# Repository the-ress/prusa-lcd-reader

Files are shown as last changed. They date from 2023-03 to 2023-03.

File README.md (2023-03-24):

# Prusa LCD Reader

Connects to flat ribbon cable no. 1 of Prusa MK3S or similar, listens to LCD
communication, and sends the text to Home Assistant.

## How it looks

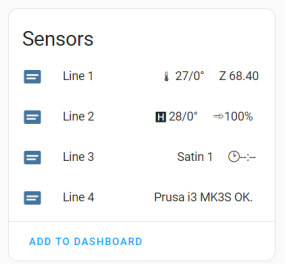
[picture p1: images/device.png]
Screenshot of device sensors line 1 to 4 in Home Assistant.

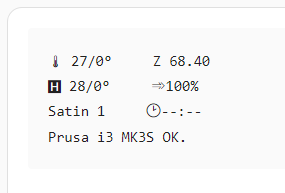
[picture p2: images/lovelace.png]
Screenshot of a Lovelace card mirroring the LCD.


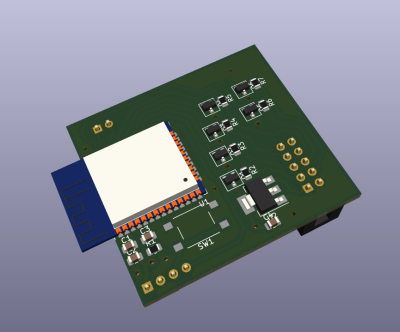
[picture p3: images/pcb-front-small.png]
Rendering of the PCB, front.

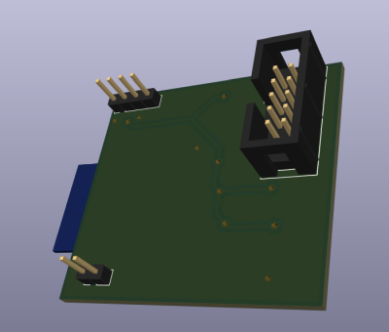
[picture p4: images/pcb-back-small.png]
Rendering of the PCB, back.

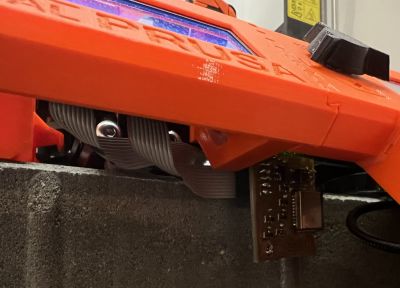
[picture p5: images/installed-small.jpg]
Photo of the board installed on the printer, underneath the LCD assembly.


## Preparing the printer

Get a [10-pin IDC connector](https://www2.mouser.com/ProductDetail/Wurth-Elektronik/61201023021?qs=W%252B2sBeLta1Y7QgcPlTMBZQ%3D%3D)
and carefully attach it to flat ribbon cable no. 1, approximately where you want
the device to go. Make sure the orientation matches the other connectors.

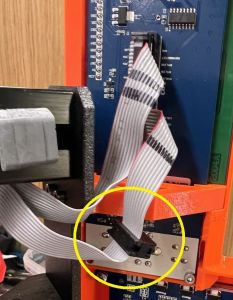
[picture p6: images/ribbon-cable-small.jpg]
Photo of the ribbon cable with the extra connector attached.


## Manufacturing notes

The board design doesn't rely on plated through-holes for the headers. (It still needs
some vias though.)

If you have the board manufactured profesionally, add some vias under pad 39 of
the ESP for better thermal performance.

### Components

- ESP32-WROOM-32
- voltage regulator 5V to 3.3V - SOT-233-3 footprint
- 6 NPN transistors (to protect GPIO from 5V signal) - SOT-23-3 footprint
- various resistors and capacitors - 0805 footprint
- 10-pin IDC connector header
- a reset button (optional)
- additional pin headers for the initial flashing (optional if you can bodge the
  connection without them)

## Sample ESPHome configuration
```yaml
external_components:
  - source: github://the-ress/prusa-lcd-reader@main
    components:
      - prusa_lcd

prusa_lcd:
  data_pins:
    - GPIO21
    - GPIO17
    - GPIO22
    - GPIO16
  enable_pin: GPIO19
  rs_pin: GPIO18
  text_sensors:
    - name: "Line 1"
    - name: "Line 2"
    - name: "Line 3"
    - name: "Line 4"
```

## Sample Lovelace card
````yaml
type: markdown
content: |-
  ```
  {{ states('sensor.printer_lcd_line_1') }}
  {{ states('sensor.printer_lcd_line_2') }}
  {{ states('sensor.printer_lcd_line_3') }}
  {{ states('sensor.printer_lcd_line_4') }}
  ```
````

## Resources
- Decoder code adapted from https://github.com/fsalomon/HD44780-decoder/
- Special characters mapping: https://github.com/prusa3d/Prusa-Firmware/blob/MK3/Firmware/lcd.h#L199
- LCD board docs: https://reprap.org/wiki/RepRapDiscount_Smart_Controller
- Printer main board schematic: https://github.com/ultimachine/Einsy-Rambo/blob/1.1a/board/Project%20Outputs/Schematic%20Prints_Einsy%20Rambo_1.1a.PDF

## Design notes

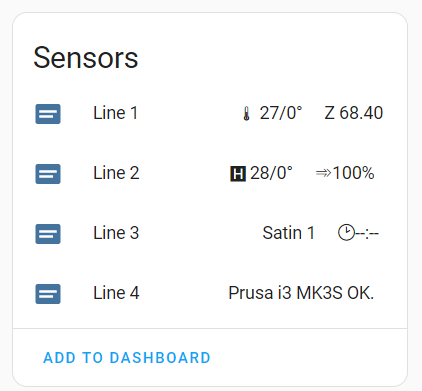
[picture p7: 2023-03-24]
images/2device.png

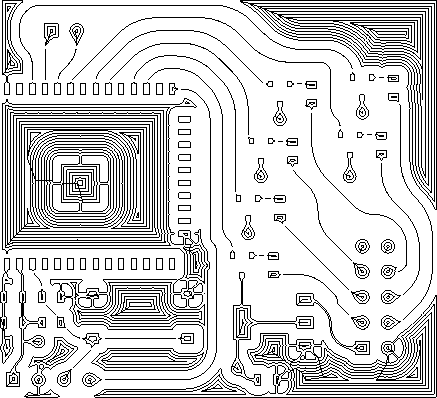
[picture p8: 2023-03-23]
other/prusa-lcd-reader-rounded-F_Cu.gbr_mt_paint_cnc_adjusted.png

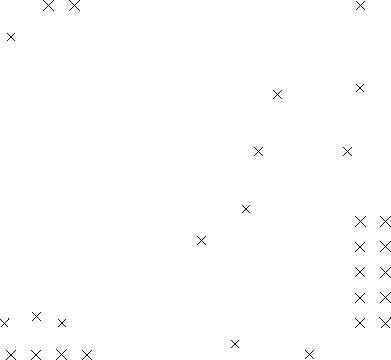
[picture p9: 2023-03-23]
other/prusa-lcd-reader-rounded_drill.png

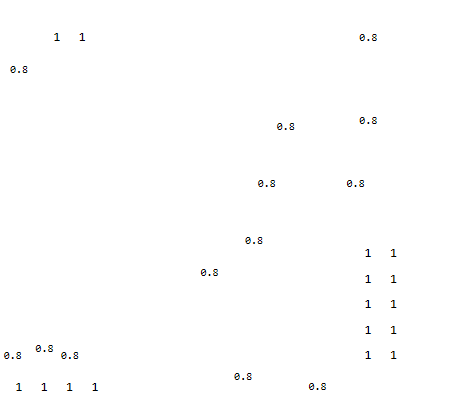
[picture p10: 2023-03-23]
other/prusa-lcd-reader-rounded_drill_map.png

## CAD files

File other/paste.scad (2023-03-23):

//mirror([0, 0, 1]) // B
stencil();

module edge(){
    import("Edge_Cuts.gbr_svg.svg");
}

module paste(){
    difference(){
        import("F_Paste.gbr_iso_joined_svg.svg");
        edge();
    }
}

module pins(){
    difference(){
        import("drl_edit_conv_joined_svg.svg");
        edge();
    }
}

module stencil(){
    union(){
        difference(){
            hull(){
                linear_extrude(height = 0.15) {
                    offset(5) edge();
                }
            }
            linear_extrude(height = 1, center = true) {
                    paste();
            }
        }
        translate([0, 0, -.45]){
            linear_extrude(height = .45) {
                pins();
            }
        }
//        translate([0, 0, 0.125 + 0.10]){
//            hull(){
//                linear_extrude(height = 0.2) {
//                    edge();
//                }
//            }
//        }
    }
}

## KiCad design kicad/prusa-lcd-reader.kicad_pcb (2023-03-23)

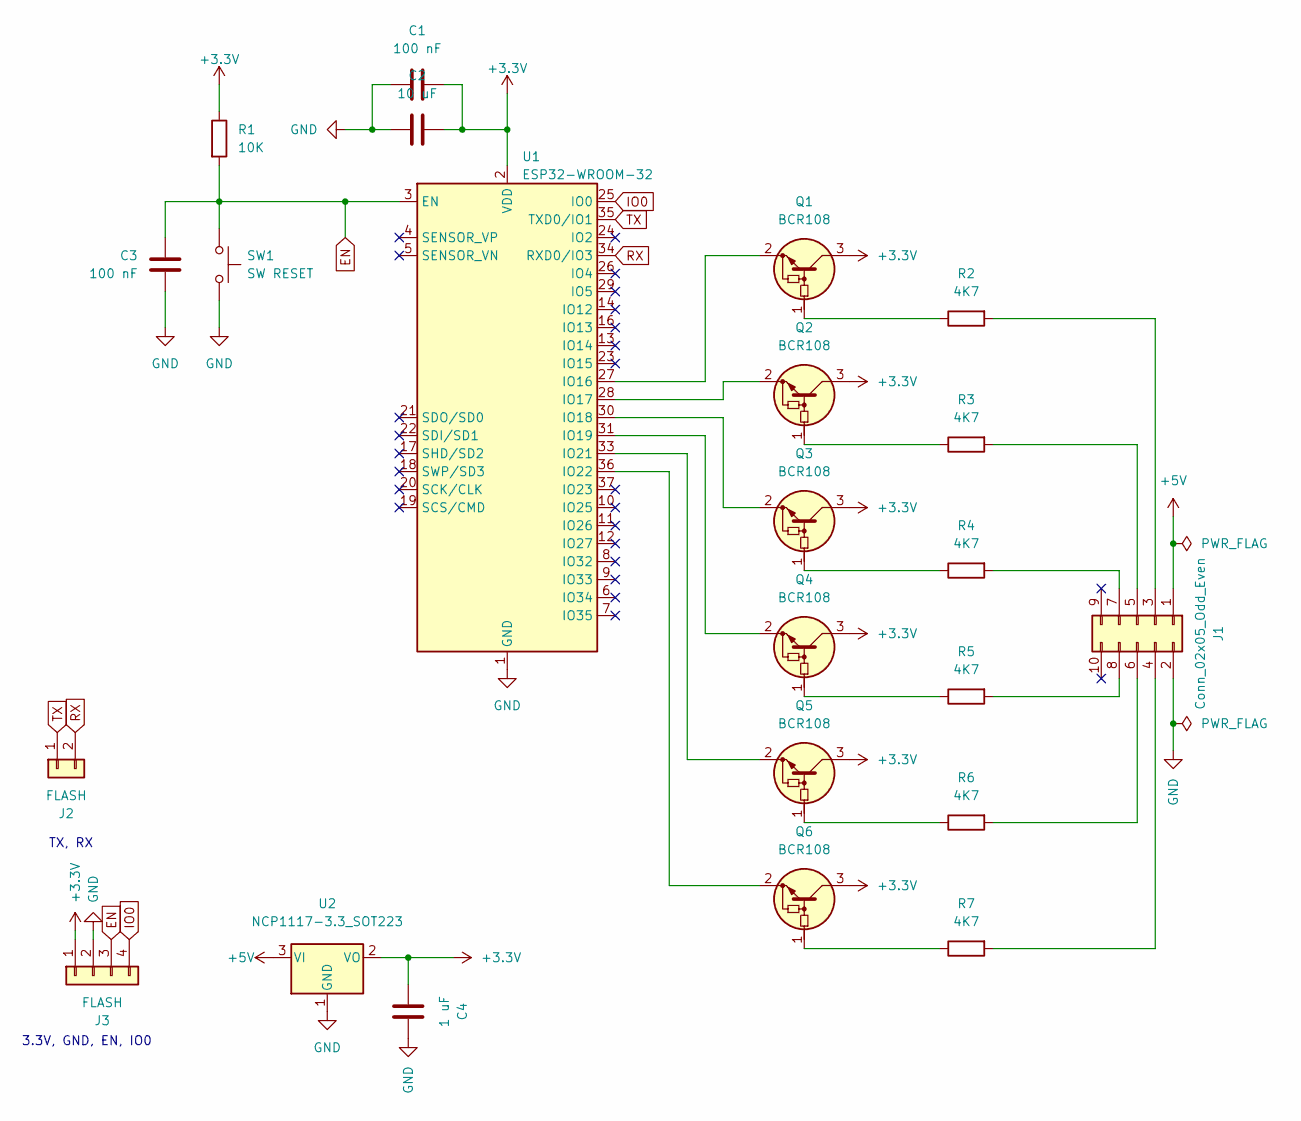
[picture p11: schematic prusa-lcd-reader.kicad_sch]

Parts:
C1, C3: 100 nF; C_0805_2012Metric
C2: 10 uF; C_0805_2012Metric
C4: 1 uF; C_0805_2012Metric
J1: Conn_02x05_Odd_Even
J2: FLASH; PinHeader_1x02_P2.54mm_Vertical
J3: FLASH; PinHeader_1x04_P2.54mm_Vertical
Q1, Q2, Q3, Q4, Q5, Q6: BCR108; SOT-23
R1: 10K; R_0805_2012Metric
R2, R3, R4, R5, R6, R7: 4K7; R_0805_2012Metric
SW1: SW RESET; SW_Push_TD-03XA-T
U1: ESP32-WROOM-32
U2: NCP1117-3.3_SOT223; SOT-223-3_TabPin2

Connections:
+3.3V: C1.2, C2.2, C4.1, J3.1, Q1.3 (C), Q2.3 (C), Q3.3 (C), Q4.3 (C), Q5.3 (C), Q6.3 (C), R1.1, U1.2 (VDD), U2.2 (VO)
+5V: J1.1, U2.3 (VI)
EN: C3.1, J3.3, R1.2, SW1.1, U1.3 (EN)
GND: C1.1, C2.1, C3.2, C4.2, J1.2, J3.2, SW1.2, U1.1 (GND), U1.15 (GND), U1.38 (GND), U1.39 (GND), U2.1 (GND)
IO0: J3.4, U1.25 (IO0)
unnamed: J1.3, R2.2
unnamed: J1.4, R7.2
unnamed: J1.5, R3.2
unnamed: J1.6, R6.2
unnamed: J1.7, R4.2
unnamed: J1.8, R5.2
unnamed: Q1.1 (B), R2.1
unnamed: Q1.2 (E), U1.27 (IO16)
unnamed: Q2.1 (B), R3.1
unnamed: Q2.2 (E), U1.28 (IO17)
unnamed: Q3.1 (B), R4.1
unnamed: Q3.2 (E), U1.30 (IO18)
unnamed: Q4.1 (B), R5.1
unnamed: Q4.2 (E), U1.31 (IO19)
unnamed: Q5.1 (B), R6.1
unnamed: Q5.2 (E), U1.33 (IO21)
unnamed: Q6.1 (B), R7.1
unnamed: Q6.2 (E), U1.36 (IO22)
RX: J2.2, U1.34 (RXD0/IO3)
TX: J2.1, U1.35 (TXD0/IO1)

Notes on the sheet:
3.3V, GND, EN, IO0
TX, RX

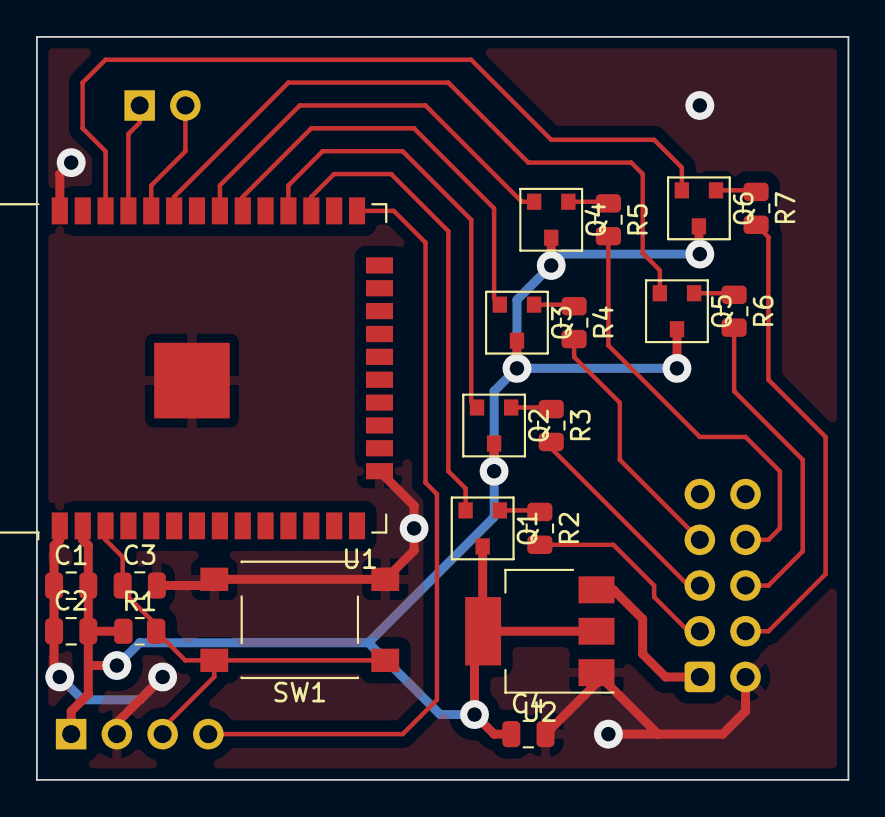
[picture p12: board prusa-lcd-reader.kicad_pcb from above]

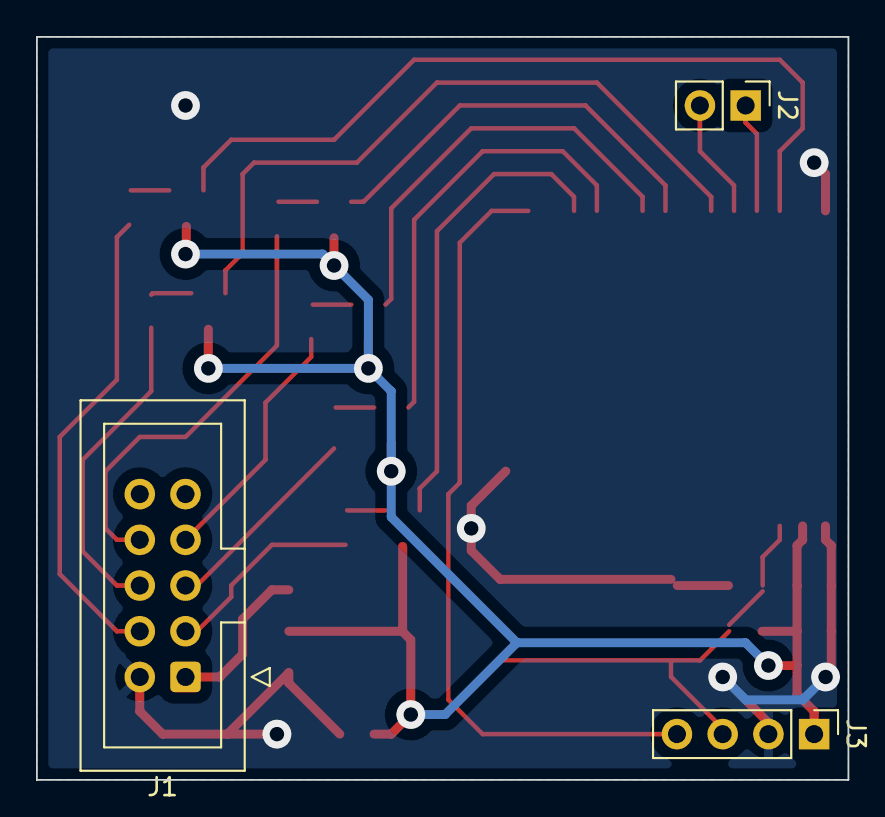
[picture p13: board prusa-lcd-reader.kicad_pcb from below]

Board: 2 copper layers, 45.1 x 41.3 mm, 23 parts (3 on the bottom side), 25 nets.

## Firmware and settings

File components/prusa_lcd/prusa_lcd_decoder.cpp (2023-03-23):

#include "prusa_lcd_decoder.h"

#include <freertos/task.h>
#include "esphome/core/log.h"

namespace esphome {
namespace prusa_lcd {

static const char *const TAG = "prusa_lcd";

void PrusaLcdDecoder::setup() {
  interruptQueue_ = xQueueCreate(64, sizeof(int));
  xTaskCreate(decodeTask_, "DecodeTask", 2048, this, 1, NULL);

	gpio_set_intr_type(enable_pin_, GPIO_INTR_NEGEDGE);
	gpio_intr_enable(enable_pin_);

  gpio_install_isr_service(0);
  gpio_isr_handler_add(enable_pin_, gpioInterruptHandler_, this);
}

void PrusaLcdDecoder::gpioInterruptHandler_(void *arg) {
  PrusaLcdDecoder *obj = (PrusaLcdDecoder*)arg;

  uint8_t rs = gpio_get_level(obj->rs_pin_);
  uint8_t d7 = gpio_get_level(obj->d7_pin_);
  uint8_t d6 = gpio_get_level(obj->d6_pin_);
  uint8_t d5 = gpio_get_level(obj->d5_pin_);
  uint8_t d4 = gpio_get_level(obj->d4_pin_);

  uint8_t data = (rs << 7) + (d7 << 3) + (d6 << 2) + (d5 << 1) + d4;
  xQueueSendFromISR(obj->interruptQueue_, &data, NULL);
}

void PrusaLcdDecoder::decodeTask_(void *arg) {
  PrusaLcdDecoder *obj = (PrusaLcdDecoder*)arg;

  uint8_t data;
  while (true) {
    if (xQueueReceive(obj->interruptQueue_, &data, portMAX_DELAY)) {
      obj->decode_(data & 0xF, data >> 7);
    }
  }
}

void PrusaLcdDecoder::decode_(uint8_t data, bool rs) {
  if (gotUpperNibble_) {
    data = (upperNibble_ << 4 | data);
    gotUpperNibble_ = false;
  } else {
    upperNibble_ = data;
    gotUpperNibble_ = true;
    return;
  }
  if (rs == 1) {
    // store received byte
    if (receivingCgram_) {
      CGRAM[cgramIndex_] = data;
      cgramIndex_ = (cgramIndex_ + 1) % CGRAM_SIZE;
    } else if (receivingDdram_) {
      DDRAM[ddramIndex_] = data;
      ddramIndex_ = (ddramIndex_ + 1) % DDRAM_SIZE;
    }
  } else {
    // command received
    evalCommand_(data);
  }
}

const uint8_t LCD_CLEAR =  0x01;
const uint8_t LCD_CLEAR_MASK = 0xFF;

const uint8_t LCD_RETURN_HOME =  0x02;
const uint8_t LCD_RETURN_HOME_MASK = 0xFE;

const uint8_t LCD_SETDDRAMADDR = 0x80;
const uint8_t LCD_SETDDRAMADDR_MASK = 0x80;

const uint8_t LCD_SETCGRAMADDR = 0x40;
const uint8_t LCD_SETCGRAMADDR_MASK = 0xC0;

const uint8_t LCD_SETFUNCTION_4BIT = 0x20;
const uint8_t LCD_SETFUNCTION_8BIT = 0x30;
const uint8_t LCD_SETFUNCTION_MASK = 0xF0;

void PrusaLcdDecoder::evalCommand_(uint8_t command) {
  receivingCgram_ = false;
  receivingDdram_ = false;

  if ((command & LCD_CLEAR_MASK) == LCD_CLEAR) {
    DDRAM.fill(32);
    ddramIndex_ = 0;
    return;
  }
  if ((command & LCD_RETURN_HOME_MASK) == LCD_RETURN_HOME) {
    ddramIndex_ = 0;
    return;
  }
  if ((command & LCD_SETCGRAMADDR_MASK) == LCD_SETCGRAMADDR) {
    cgramIndex_ = (command & 0x3f) % CGRAM_SIZE;
    receivingCgram_ = true;
    return;
  }
  if ((command & LCD_SETDDRAMADDR_MASK) == LCD_SETDDRAMADDR) {
    ddramIndex_ = (command & 0x7f) % DDRAM_SIZE;
    receivingDdram_ = true;
    return;
  }

  // unknown command
}

void PrusaLcdDecoder::set_data_pins(std::array<uint8_t, 4> pins) {
  this->d4_pin_ = (gpio_num_t)pins[0];
  this->d5_pin_ = (gpio_num_t)pins[1];
  this->d6_pin_ = (gpio_num_t)pins[2];
  this->d7_pin_ = (gpio_num_t)pins[3];
}
void PrusaLcdDecoder::set_enable_pin(uint8_t enable_pin) { this->enable_pin_ = (gpio_num_t)enable_pin; }
void PrusaLcdDecoder::set_rs_pin(uint8_t rs_pin) { this->rs_pin_ = (gpio_num_t)rs_pin; }

void PrusaLcdDecoder::dump_config() {
  ESP_LOGCONFIG(TAG, "  Enable Pin: %d", enable_pin_);
  ESP_LOGCONFIG(TAG, "  RS Pin: %d", rs_pin_);
  ESP_LOGCONFIG(TAG, "  Data Pins:");
  ESP_LOGCONFIG(TAG, "    D4: %d", d4_pin_);
  ESP_LOGCONFIG(TAG, "    D5: %d", d5_pin_);
  ESP_LOGCONFIG(TAG, "    D6: %d", d6_pin_);
  ESP_LOGCONFIG(TAG, "    D7: %d", d7_pin_);
}

void PrusaLcdDecoder::dump_ddram() {
  ESP_LOGD(TAG, "DDRAM:");
  for (int i = 0; i < DDRAM_SIZE; i++) {
    ESP_LOGD(TAG, "  %d = %d (%c)", i, DDRAM[i], DDRAM[i]);
  }
}

void PrusaLcdDecoder::dump_cgram() {
  ESP_LOGD(TAG, "CGRAM:");
  for (int a = 0; a < 8; a++) {
    ESP_LOGD(TAG, "  %d:", a);
    for (int i = 0; i < 8; i++) {
      char m = 16;
      char x = CGRAM[a * 8 + i];
      char line[6] = { 0 };
      for (int j = 0; j < 5; j++) {
        if (x & m) {
          line[j] = 'x';
        } else {
          line[j] = ' ';
        }
        m >>= 1;
      }

      ESP_LOGD(TAG, "    %s", line);
    }
  }
}

}  // namespace prusa_lcd
}  // namespace esphome

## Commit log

2023-03-23 Add existing code
    [paste.scad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]
2023-03-24 Add images and sample lovelace card
